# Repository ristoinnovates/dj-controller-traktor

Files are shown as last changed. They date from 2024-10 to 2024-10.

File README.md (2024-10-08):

# DJ Controller for Traktor (Modeled after Traktor Kontrol S2 MK2)

DJ Controller

## Overview

This is a custom DJ Controller designed to work with the DJ software **Traktor**, modeled after the **Traktor Kontrol S2 MK2**. This controller is featured in my YouTube video, and it’s a fully DIY project using a variety of components, including mechanical switches, rotary encoders, and sliding potentiometers, all housed in a custom 3D-printed enclosure.

🎬 **Watch the full build video on YouTube**: [Watch Now](https://www.youtube.com/watch?v=orAAT4ew4GM)

## Features

- **22 Mechanical Switches**: Blue clicky type, paired with custom purple keycaps.
- **8 Rotary Encoders**: Provides precise control for effects and settings.
- **18 Pushbuttons**: Fully customizable, paired with caps.
- **5 Sliding Potentiometers**: 45mm for faders or other continuous controls.
- **18 RV09 Potentiometers**: For knobs and other controls.
- **1 CD4051BE Multiplexer**: Handles multiple inputs.
- **4 CD74HC4067 Multiplexers**: Expands the controller’s functionality.
- **Custom PCB**: Designed specifically for this controller.
- **Custom 3D Printed Enclosure**: Includes top and bottom parts, built to house all components securely.
- **Heat Set Inserts & Screws**: Provides durability and easy assembly.

## Components

- **Mechanical Switches**: Blue clicky type
- **Rotary Encoders**
- **Pushbuttons**
- **Potentiometers**: RV09 and sliding potentiometers
- **Multiplexers**: CD4051BE and CD74HC4067

For more details and assembly instructions, visit the product page: [DJ Controller Files on RistoInnovates.com](https://ristoinnovates.com/product/dj-controller-files/)

## Downloads

- **Arduino Code, STL Files & Schematics**: [Download Here](https://ristoinnovates.com/product/dj-controller-files/) (Free)
- **Prebuilt DJ Controller**: [Buy a Fully Assembled Unit](https://ristoinnovates.com/product/dj-controller/)

## How to Build

1. Print the 3D enclosure using the provided STL files.
2. Assemble all components based on the schematics.
3. Upload the Arduino code to your controller.
4. Enjoy your custom Traktor DJ controller!

---

Feel free to submit pull requests or open issues if you have improvements or ideas for the project.

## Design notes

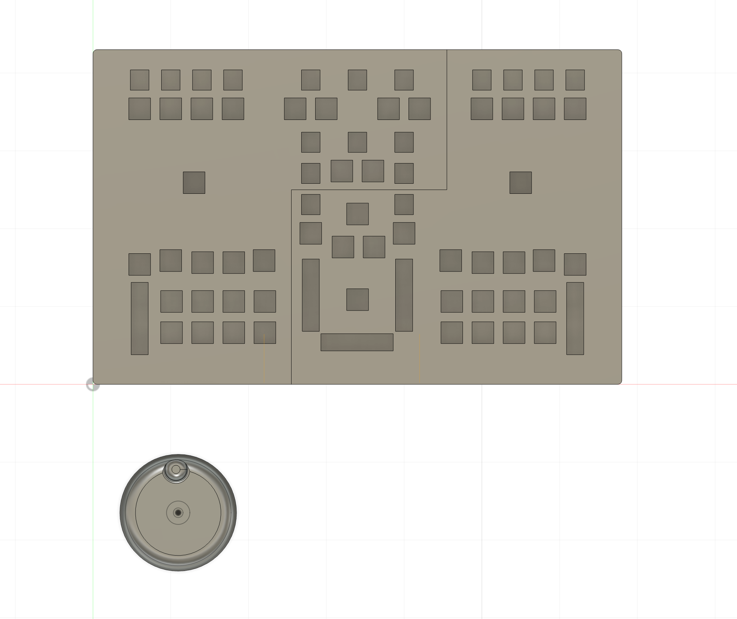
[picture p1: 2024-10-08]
DJControllerEnclosure2.png

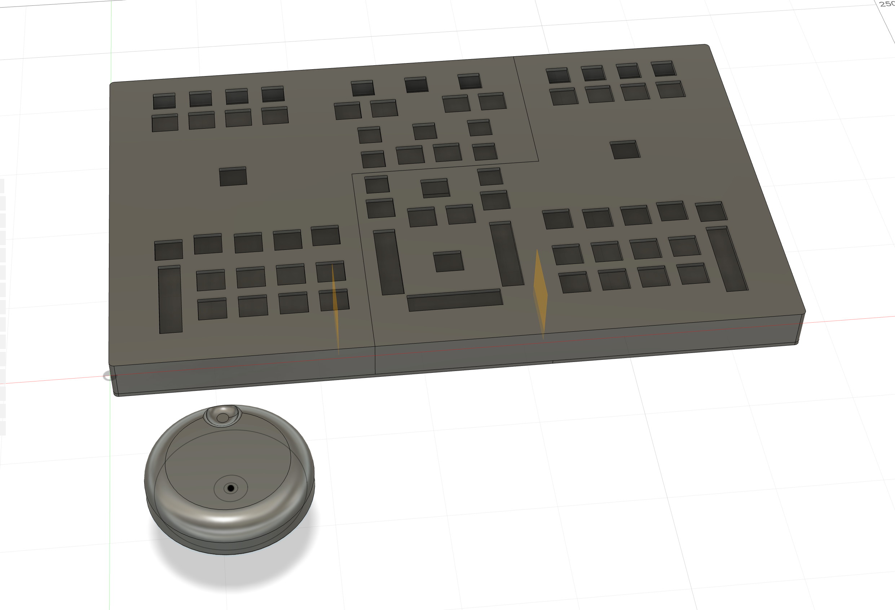
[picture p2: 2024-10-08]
DJControllerEnclosure1.png

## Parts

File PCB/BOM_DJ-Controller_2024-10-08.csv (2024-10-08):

ID | Name | Designator | Footprint | Quantity | Manufacturer Part | Manufacturer | Supplier | Supplier Part | Price | Pins | 3DModel | Contributor | JLCPCB Part Class | link
1 | B3F-4055 | KEY1,KEY2,KEY3,KEY4,KEY5,KEY6,KEY7,KEY8,KEY9,KEY10,KEY11,KEY12,KEY13,KEY14,KEY15,KEY16,KEY17,KEY18 | KEY-TH_4P-L12.0-W12.0-P5.00-LS13.4-EH | 18 | B3F-4055 | OMRON(欧姆龙) | LCSC | C84931 | 0.09 | 4 | push button b3f-4055 with cap | thorikidis | Extended Part
2 | cherry | U5,U6,U7,U8,U9,U10,U11,U12,U13,U14,U15,U16,U17,U18,U19,U20,U21,U22,U23,U24,U25,U26 | CHERRY | 22 |  |  |  |  |  | 2 | SW_CHERRY_MX | rh726543
3 | EC11 | V1,V2,V3,V4,V5,V6,V7,V8 | EC11 | 8 |  |  | LCSC |  |  | 7 | EC11E_ENCODER | jc888
4 | RV09AF-40-15K-B10K | R1,R2,R3,R4,R5,R6,R7,R8,R9,R10,R11,R12,R13,R14,R15,R16,R17,R18 | RES-ADJ-TH_RV09 | 18 | RV09AF-40-15K-B10K | null | LCSC | C5151445 |  | 5 | RES-ADJ-TH_RV09 | lcsc |  | https://img.jlc.com/pdf/applyPasteComponent/2021-08-01/763763S/362e4adb360c4c289389522589d80c5d/5K%E9%95%BF%E6%9F%84%E6%97%8B%E8%BD%AC%E7%94%B5%E4%BD%8D%E5%99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
5 | TRIMSLIDE45 | TM1,TM2,TM3,TM4,TM5 | SLIDEPOT-45 | 5 |  |  |  |  |  | 7 |  | steklausen21
6 | E.d.cd4051be | MUXPOT2 | CD4051BE | 1 |  |  |  |  |  | 16 | CD74HC4051EE4 | sharif1992
7 | Arduino Pro Micro | U1 | ARDUINO PRO MICRO TYPE-C | 1 |  |  |  |  |  | 24 | ARDUINO-PRO-MICRO_USB-C | wade.kerrick
8 | CD74HC4067 | MUXSW3,MUXSW1,MUXPOT1,MUXSW2 | CD74HC4067 | 4 |  |  |  |  |  | 24 | cd74hc4067 | andy vu
9 | MCP2317 MODULE 21X26MM | U3 | MMCP23017EDT | 1 |  |  |  |  |  | 30 |  | omoX5

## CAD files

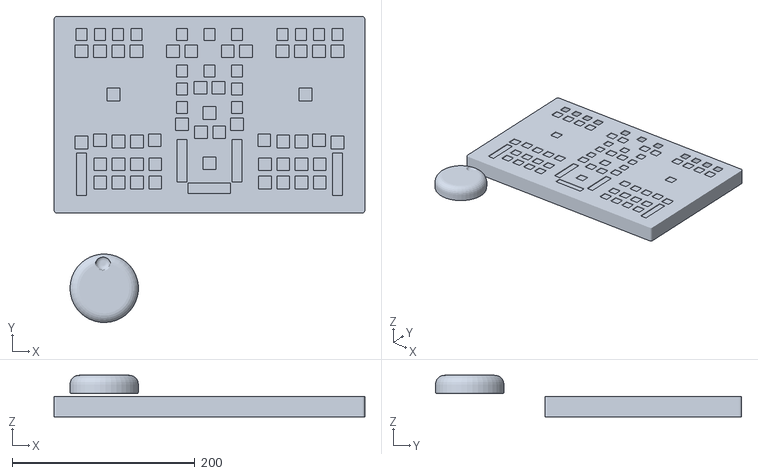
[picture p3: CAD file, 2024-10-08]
DJController STL.stl
340.0 x 335.0 x 45.5

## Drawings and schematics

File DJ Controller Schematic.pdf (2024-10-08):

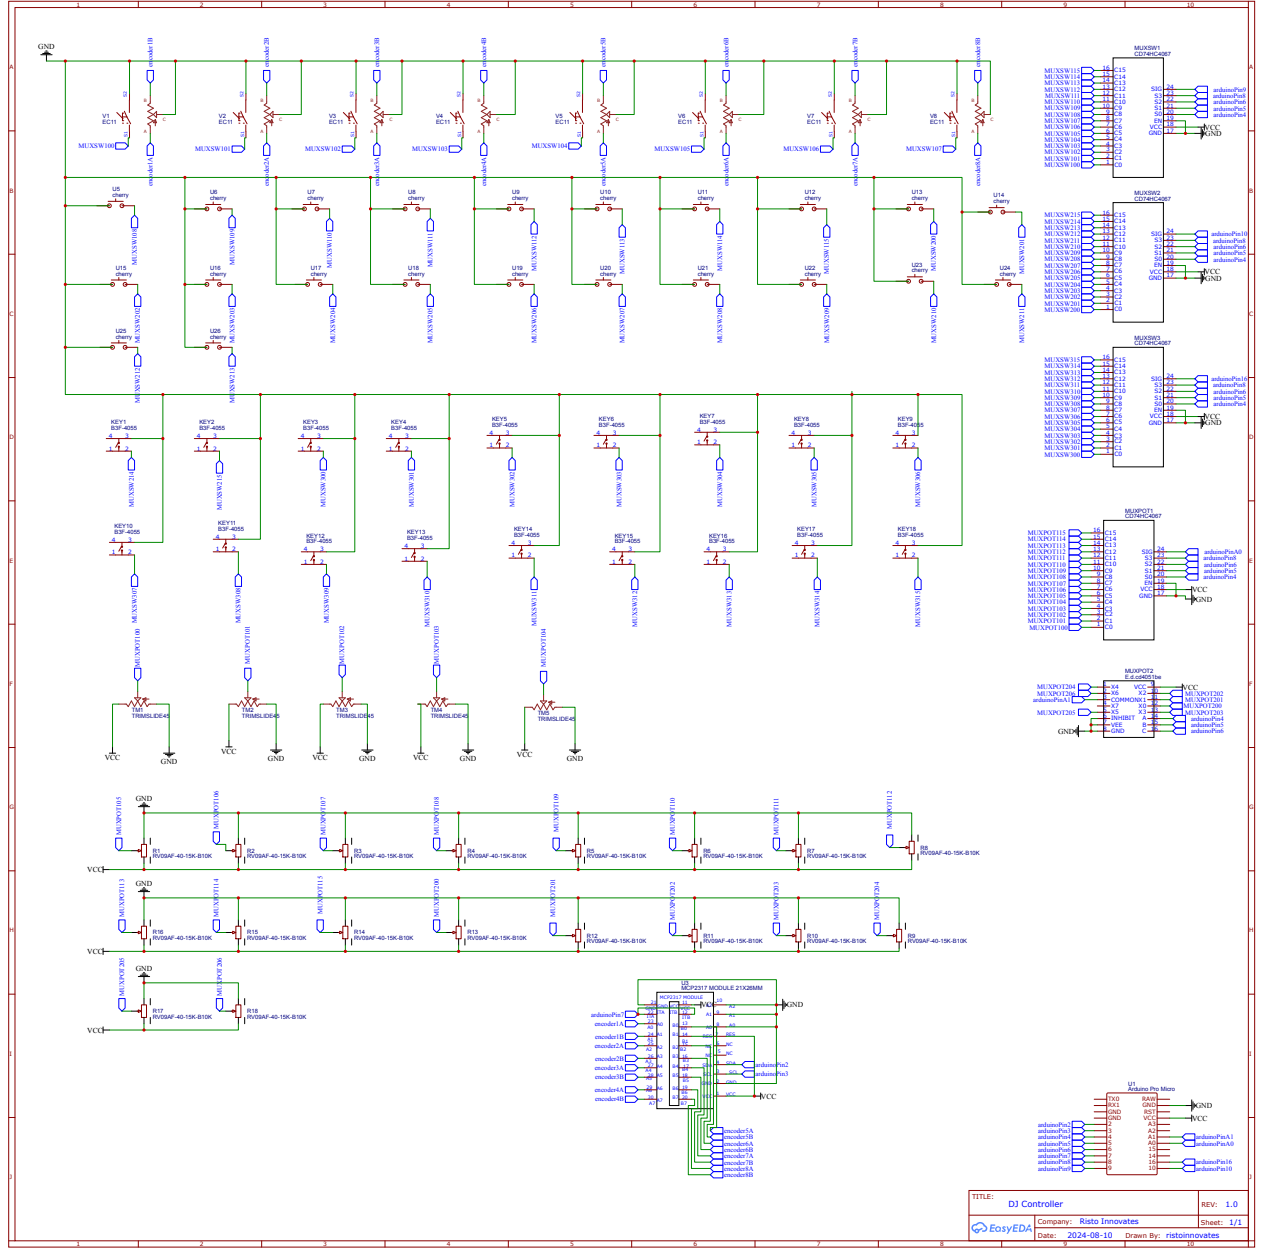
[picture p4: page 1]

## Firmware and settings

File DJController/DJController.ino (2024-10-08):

#include <Arduino.h>
#include "MIDIUSB.h"
#include <Wire.h>
#include "MCP23017Encoders.h"
#include <ResponsiveAnalogRead.h>

int startingCCPots = 1;      // Starting CC for pots
int startingCCButtons = 50;  // Starting CC for buttons
int startingCCEncoders = 100; // Starting CC for encoders




int muxChannel1 = 4;
int muxChannel2 = 5;
int muxChannel3 = 6;
int muxChannel4 = 8;

int muxSwitchesInput1 = 9; // 16 channel digital
int muxSwitchesInput2 = 10; // 16 channel digital
int muxSwitchesInput3 = 16; // 16 channel digital


int muxPotsInput1 = A0; // 16 channel analog
int muxPotsInput2 = A1; // 8 channel analog

// MULTIPLEXER 1 BUTTONS - 16 CH
const int NUMBER_MUX_1_BUTTONS = 16;
bool muxButtons1CurrentState[NUMBER_MUX_1_BUTTONS] = {0};
bool muxButtons1PreviousState[NUMBER_MUX_1_BUTTONS] = {0};

unsigned long lastDebounceTimeMUX1[NUMBER_MUX_1_BUTTONS] = {0};
unsigned long debounceDelayMUX1 = 20;

// MULTIPLEXER 2 BUTTONS - 16 CH
const int NUMBER_MUX_2_BUTTONS = 16;
bool muxButtons2CurrentState[NUMBER_MUX_2_BUTTONS] = {0};
bool muxButtons2PreviousState[NUMBER_MUX_2_BUTTONS] = {0};

unsigned long lastDebounceTimeMUX2[NUMBER_MUX_2_BUTTONS] = {0};
unsigned long debounceDelayMUX2 = 20;

// MULTIPLEXER 3 BUTTONS - 16 CH
const int NUMBER_MUX_3_BUTTONS = 16;
bool muxButtons3CurrentState[NUMBER_MUX_3_BUTTONS] = {0};
bool muxButtons3PreviousState[NUMBER_MUX_3_BUTTONS] = {0};

unsigned long lastDebounceTimeMUX3[NUMBER_MUX_3_BUTTONS] = {0};
unsigned long debounceDelayMUX3 = 20;


// MULTIPLEXER 1 POTS - 16 CH
const int NUMBER_MUX_1_POTS = 16;
int muxPots1CurrentValue[NUMBER_MUX_1_POTS] = {0};
int muxPots1PreviousValue[NUMBER_MUX_1_POTS] = {0};

ResponsiveAnalogRead potsMux1[NUMBER_MUX_1_POTS] = {
  ResponsiveAnalogRead(A0, true), 
  ResponsiveAnalogRead(A0, true), 
  ResponsiveAnalogRead(A0, true), 
  ResponsiveAnalogRead(A0, true), 
  ResponsiveAnalogRead(A0, true), 
  ResponsiveAnalogRead(A0, true), 
  ResponsiveAnalogRead(A0, true), 
  ResponsiveAnalogRead(A0, true), 
  ResponsiveAnalogRead(A0, true), 
  ResponsiveAnalogRead(A0, true), 
  ResponsiveAnalogRead(A0, true), 
  ResponsiveAnalogRead(A0, true), 
  ResponsiveAnalogRead(A0, true), 
  ResponsiveAnalogRead(A0, true), 
  ResponsiveAnalogRead(A0, true), 
  ResponsiveAnalogRead(A0, true)
};


// MULTIPLEXER 2 POTS - 8 CH
const int NUMBER_MUX_2_POTS = 7;
int muxPots2CurrentValue[NUMBER_MUX_2_POTS] = {0};
int muxPots2PreviousValue[NUMBER_MUX_2_POTS] = {0};



ResponsiveAnalogRead potsMux2[NUMBER_MUX_2_POTS] = {
  ResponsiveAnalogRead(A1, true), 
  ResponsiveAnalogRead(A1, true), 
  ResponsiveAnalogRead(A1, true),
  ResponsiveAnalogRead(A1, true), 
  ResponsiveAnalogRead(A1, true), 
  ResponsiveAnalogRead(A1, true), 
  ResponsiveAnalogRead(A1, true),
};




// Encoders
const int numberOfEncoders = 8;
MCP23017Encoders myMCP23017Encoders(7); // Parameter is the Arduino interrupt pin that the MCP23017 is connected to

int previousValues[numberOfEncoders] = {0}; // Array to store previous values of each encoder

void setup()
{
  Serial.begin(9600);

  pinMode(muxChannel1, OUTPUT);
  pinMode(muxChannel2, OUTPUT);
  pinMode(muxChannel3, OUTPUT);
  pinMode(muxChannel4, OUTPUT);
  digitalWrite(muxChannel1, LOW);
  digitalWrite(muxChannel2, LOW);
  digitalWrite(muxChannel3, LOW);
  digitalWrite(muxChannel4, LOW);

  pinMode(muxSwitchesInput1, INPUT_PULLUP); // Digital input for the first set of switches
  pinMode(muxSwitchesInput2, INPUT_PULLUP); // Digital input for the second set of switches
  pinMode(muxSwitchesInput3, INPUT_PULLUP); // Digital input for the second set of switches

  pinMode(muxPotsInput1, INPUT); // Analog input for the first set of pots
  pinMode(muxPotsInput2, INPUT); // Analog input for the second set of pots

  myMCP23017Encoders.begin();
  myMCP23017Encoders.setAccel(0, 100);
}

void loop()
{
  updateEncoders();
  updateMUXButtons(muxSwitchesInput1, NUMBER_MUX_1_BUTTONS, muxButtons1CurrentState, muxButtons1PreviousState, lastDebounceTimeMUX1, debounceDelayMUX1, 1);
  updateMUXButtons(muxSwitchesInput2, NUMBER_MUX_2_BUTTONS, muxButtons2CurrentState, muxButtons2PreviousState, lastDebounceTimeMUX2, debounceDelayMUX2, 2);
  updateMUXButtons(muxSwitchesInput3, NUMBER_MUX_3_BUTTONS, muxButtons3CurrentState, muxButtons3PreviousState, lastDebounceTimeMUX3, debounceDelayMUX3, 3);

  updateMUXPots(muxPotsInput1, NUMBER_MUX_1_POTS, muxPots1CurrentValue, muxPots1PreviousValue, 1);
  updateMUXPots(muxPotsInput2, NUMBER_MUX_2_POTS, muxPots2CurrentValue, muxPots2PreviousValue, 2);

  
}

void updateEncoders() {
  for (int i = 0; i < numberOfEncoders; i++)
  {
    int currentValue = myMCP23017Encoders.read(i);

    if (currentValue != previousValues[i])
    {
      Serial.print("Encoder ");
      Serial.print(i);
      Serial.print(": ");
      Serial.println(currentValue);
      byte ccNumber = startingCCEncoders + i;  // Use the encoder index to assign a CC number
      int delta = currentValue - previousValues[i];
      byte ccValue = (delta > 0) ? 1 : 127;  // Send 1 for clockwise, 127 for counterclockwise

      midiControlChange(0, ccNumber, ccValue);  // Send MIDI CC message
      
      previousValues[i] = currentValue;
    }
  }
}

void updateMUXButtons(int muxInputPin, int numberOfButtons, bool *currentState, bool *previousState, unsigned long *lastDebounceTime, unsigned long debounceDelay, int muxNumber) {
  for (int i = 0; i < numberOfButtons; i++) {
    int A = (i >> 0) & 1;  // Extract the least significant bit
    int B = (i >> 1) & 1;  // Extract the second bit
    int C = (i >> 2) & 1;  // Extract the third bit
    int D = (i >> 3) & 1;  // Extract the most significant bit
    
    digitalWrite(muxChannel1, A);  // A corresponds to the least significant bit
    digitalWrite(muxChannel2, B);  // B corresponds to the second bit
    digitalWrite(muxChannel3, C);  // C corresponds to the third bit
    digitalWrite(muxChannel4, D);  // D corresponds to the most significant bit
    
    //delay(1);  // Add a longer delay for debugging

    currentState[i] = digitalRead(muxInputPin);

    if ((millis() - lastDebounceTime[i]) > debounceDelay) {
      if (currentState[i] != previousState[i]) {
        lastDebounceTime[i] = millis();

        if (currentState[i] == LOW) {
          Serial.print("MUX: ");
          Serial.print(muxNumber);
          Serial.print(", Button: ");
          Serial.println(i);
          pressButton(muxNumber, i, 1);
        } else {
          pressButton(muxNumber, i, 0);
        }

        previousState[i] = currentState[i];
      }
    }
  }
}

void pressButton(int muxNumber, int buttonNumber, int state) {
  byte ccNumber = startingCCButtons + (muxNumber - 1) * NUMBER_MUX_1_BUTTONS + buttonNumber;
  byte ccValue = (state == 1) ? 127 : 0;  // Send 127 for button press, 0 for release

  midiControlChange(0, ccNumber, ccValue);  // Send MIDI CC message
}



void updateMUXPots(int muxInputPin, int numberOfPots, int *currentValue, int *previousValue, int muxNumber) {
  for (int i = 0; i < numberOfPots; i++) {
    int A = (i >> 0) & 1;
    int B = (i >> 1) & 1;
    int C = (i >> 2) & 1;
    int D = (i >> 3) & 1;

    // Set the channel selection for the multiplexer
    digitalWrite(muxChannel1, A);
    digitalWrite(muxChannel2, B);
    digitalWrite(muxChannel3, C);

    if (muxNumber == 1) { // 16-channel multiplexer
      digitalWrite(muxChannel4, D);  // D is only used for the 16-channel mux
    }

    //delay(1);  // Small delay for stable channel switching

    if (muxNumber == 1) {
      potsMux1[i].update();  // Update the analog value reading for Mux 1
      currentValue[i] = potsMux1[i].getValue();  // Handle responsive analog read
    } else if (muxNumber == 2) {
      potsMux2[i].update();
      currentValue[i] = potsMux2[i].getValue();
    }

    if (currentValue[i] != previousValue[i]) {
      Serial.print("MUX: ");
      Serial.print(muxNumber);
      Serial.print(", Pot: ");
      Serial.print(i);
      Serial.print(" Value: ");
      Serial.println(currentValue[i]);
      handlePots(muxNumber, i, currentValue[i]);
      previousValue[i] = currentValue[i];  // Update the previous value
    }
  }
}



void handlePots(int muxNumber, int potNumber, int value) {
  byte ccNumber = startingCCPots;

  // Dynamically calculate the CC number based on the multiplexer
  if (muxNumber == 1) {
    ccNumber += potNumber;  // MUX 1 pots
  } else if (muxNumber == 2) {
    ccNumber += NUMBER_MUX_1_POTS + potNumber;  // MUX 2 starts after MUX 1's pots
  }

  byte ccValue = map(value, 0, 1023, 0, 127);  // Map analog value (0-1023) to MIDI CC value (0-127)
  
  midiControlChange(0, ccNumber, ccValue);  // Send MIDI CC message
}




void midiNoteOn(byte channel, unsigned short note) {
  midiEventPacket_t midiNoteOn = { 0x09, 0x90 | channel, note, 100 };
  MidiUSB.sendMIDI(midiNoteOn);
  MidiUSB.flush();  // Ensure the message is sent immediately
}

void midiNoteOff(byte channel, unsigned short note) {
  midiEventPacket_t midiNoteOff = { 0x08, 0x80 | channel, note, 0 };
  MidiUSB.sendMIDI(midiNoteOff);
  MidiUSB.flush();  // Ensure the message is sent immediately
}

void midiControlChange(byte channel, byte control, byte value) {
  midiEventPacket_t event = { 0x0B, 0xB0 | channel, control, value };
  MidiUSB.sendMIDI(event);
  MidiUSB.flush();  // Ensure the message is sent immediately
}

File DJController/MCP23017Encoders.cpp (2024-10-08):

#include <arduino.h>
#include "MCP23017Encoders.h"

int _MCP23017intPin;
Adafruit_MCP23X17 _mcp;

volatile struct mcpEncoder
{
    int tickValue;
    uint16_t previousBitMask;
    unsigned long msSinceLastRead;
    int currentValue;
    int previousValue; // Store previous value
    float accel;       // Accelerator value
    unsigned long lastDebounceTime; // Debouncing timer
} mcpEncoders[MCP_ENCODERS];

MCP23017Encoders::MCP23017Encoders(int intPin)
{
    _MCP23017intPin = intPin;
}

void MCP23017Encoders::begin()
{
    int i;

    _mcp.begin_I2C(); // Use default address 0

    pinMode(_MCP23017intPin, INPUT);

    _mcp.setupInterrupts(MCP_INT_MIRROR, MCP_INT_ODR, LOW); // The MCP output interrupt pin.
    for (i = 0; i < 16; i++)
    {
        _mcp.pinMode(i, INPUT_PULLUP);
        _mcp.setupInterruptPin(i, CHANGE);
    }

    _mcp.readGPIOAB(); // Initialize for interrupts.

    attachInterrupt(digitalPinToInterrupt(_MCP23017intPin), MCP23017EncoderISR, FALLING);

    for (i = 0; i < MCP_ENCODERS; i++)
    {
        mcpEncoders[i].accel = 1;
        mcpEncoders[i].msSinceLastRead = millis();
        mcpEncoders[i].previousValue = 0; // Initialize previous value
        mcpEncoders[i].lastDebounceTime = 0; // Initialize debounce timer
    }
}

int MCP23017Encoders::read(int encoder)
{
    if (encoder < 0 || encoder >= MCP_ENCODERS) return 0;

    unsigned long currentTime = millis();
    if (currentTime - mcpEncoders[encoder].lastDebounceTime > 50) // 50ms debounce delay
    {
        float w = abs(mcpEncoders[encoder].tickValue) / (currentTime - mcpEncoders[encoder].msSinceLastRead);

        if (w > 11) 
            mcpEncoders[encoder].currentValue += mcpEncoders[encoder].tickValue * mcpEncoders[encoder].accel;
        else  
            mcpEncoders[encoder].currentValue += mcpEncoders[encoder].tickValue;

        mcpEncoders[encoder].tickValue = 0;
        mcpEncoders[encoder].msSinceLastRead = currentTime;
        mcpEncoders[encoder].lastDebounceTime = currentTime;
    }

    if (mcpEncoders[encoder].currentValue != mcpEncoders[encoder].previousValue) // Check if value has changed
    {
        mcpEncoders[encoder].previousValue = mcpEncoders[encoder].currentValue; // Update previous value
        return mcpEncoders[encoder].currentValue;
    }

    return mcpEncoders[encoder].previousValue;
}

void MCP23017Encoders::write(int encoder, int value)
{
    if (encoder < 0 || encoder >= MCP_ENCODERS) return;

    mcpEncoders[encoder].currentValue = value;
    mcpEncoders[encoder].previousValue = value; // Update previous value when writing
}

void MCP23017Encoders::setAccel(int encoder, float value)
{
    if (encoder < 0 || encoder >= MCP_ENCODERS) return;

    mcpEncoders[encoder].accel = value;
}

/*
  Interrupt service
*/
static void MCP23017EncoderISR(void)
{
    uint8_t p;
    uint16_t v;

    noInterrupts();
    detachInterrupt(digitalPinToInterrupt(_MCP23017intPin));
    interrupts();

    p = _mcp.getLastInterruptPin();
    v = _mcp.readGPIOAB();

    for (int i = 0; i < 8; i++)
    {
        uint16_t mask = (0x03 << (i * 2));
        uint16_t currentBits = (v & mask) >> (i * 2);
        currentBits |= mcpEncoders[i].previousBitMask << 2;

        switch (currentBits)
        {
            case 0: case 5: case 10: case 15:
                break;

            case 1: case 7: case 8: case 14:
                mcpEncoders[i].tickValue++;
                break;

            case 2: case 4: case 11: case 13:
                mcpEncoders[i].tickValue--;
                break;
        }

        mcpEncoders[i].previousBitMask = v & mask;
    }

    EIFR = 0x01;
    attachInterrupt(digitalPinToInterrupt(_MCP23017intPin), MCP23017EncoderISR, FALLING);
}
